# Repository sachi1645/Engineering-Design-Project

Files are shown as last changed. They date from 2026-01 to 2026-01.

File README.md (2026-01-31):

# Wireless Emergency Alert System for Live Performers

> **Group Debuggers** > *Department of Electronic & Telecommunication Engineering, University of Moratuwa*

## 📖 Abstract
Live performance environments demand fast, discreet, and effective communication between performers and the technical crew. Conventional methods such as hand signals or physically reaching out to technicians are inefficient and disruptive. 

This project presents a **Wireless Emergency Alert System** designed specifically for stage performers. Built around a custom PCB featuring the **ESP32-WROOM-32** microcontroller, the wearable device enables one-touch alert transmission over a local Wi-Fi network. Alerts are displayed in real-time on a mobile-responsive web dashboard.

## 🚀 Key Features
* **Real-Time Alerts:** Instantly displays performer name, device ID, and timestamp on the dashboard when the alert button is pressed.
* **Offline Operation:** Runs entirely on a local Wi-Fi network (LAN) with no internet dependency, ensuring reliability in any venue.
* **Audible Notifications:** The dashboard triggers an alert sound to grab the crew's attention during live scenarios.
* **Cross-Platform Dashboard:** A mobile-responsive web app (Flask) that works on laptops, tablets, and phones.
* **Easy Access:** Generates a QR code for the server URL, allowing devices to join the dashboard instantly.
* **Battery Operated:** Powered by a 3.7V 500mAh Li-Po battery with up to 5 hours of active usage.

## 🛠️ Tech Stack
### Hardware
* **Microcontroller:** ESP32-WROOM-32 Chip
* **Power:** 3.7V 500mAh Li-Po Battery with TP4056 Charging Module
* **Connectivity:** 2.4GHz Wi-Fi (Local Network)
* **Interface:** Tactile Push Button, Status LED, Slide Switch

### Software
* **Firmware:** Arduino C++ (HTTP POST, UDP Discovery)
* **Backend:** Python Flask (Web Server, Alert Queue)
* **Frontend:** HTML, CSS, JavaScript (WebSockets for live updates)

## 🏗️ System Architecture
The system consists of two main parts:
1.  **Wearable Transmitter (ESP32):** Reads button inputs and sends alert data via Wi-Fi.
2.  **Central Server (Flask):** Hosted on a PC or Raspberry Pi, it receives alerts and broadcasts them to the dashboard.

**Data Flow:**
`Button Press` -> `ESP32` -> `Wi-Fi Router` -> `Flask Server` -> `Web Dashboard`

## 🔌 Hardware Specifications
| Component | Specification |
|---|---|
| **Current Draw (Idle)** | ~80-100 mA |
| **Current Draw (Peak)** | ~150-160 mA |
| **Battery Life** | ~4-5 Hours (Active) |
| **Charging Time** | ~1.5-2 Hours |

## 🚀 Getting Started

### Prerequisites
* **Hardware:** ESP32 Development Board (or custom PCB), Push Button, LED.
* **Software:** Arduino IDE, Python 3.x.

### 1. Firmware Setup (ESP32)
1.  Open the firmware folder in **Arduino IDE**.
2.  Install the `ESP32` board manager.
3.  Update the `ssid` and `password` variables to match your local router.
4.  Upload the code to the ESP32.

## 👥 Team: Group Debuggers
* **Manitha Ayanaja** - Firmware, Web App, PCB
* **Sachinthaka Dilhara** - PCB Design
* **Kaveesha Divyanga** - Enclosure Design
* **Mishen Janodya** - PCB Design

## 📄 License
This project is submitted for the **EN1190 Engineering Design Project** module at the University of Moratuwa.

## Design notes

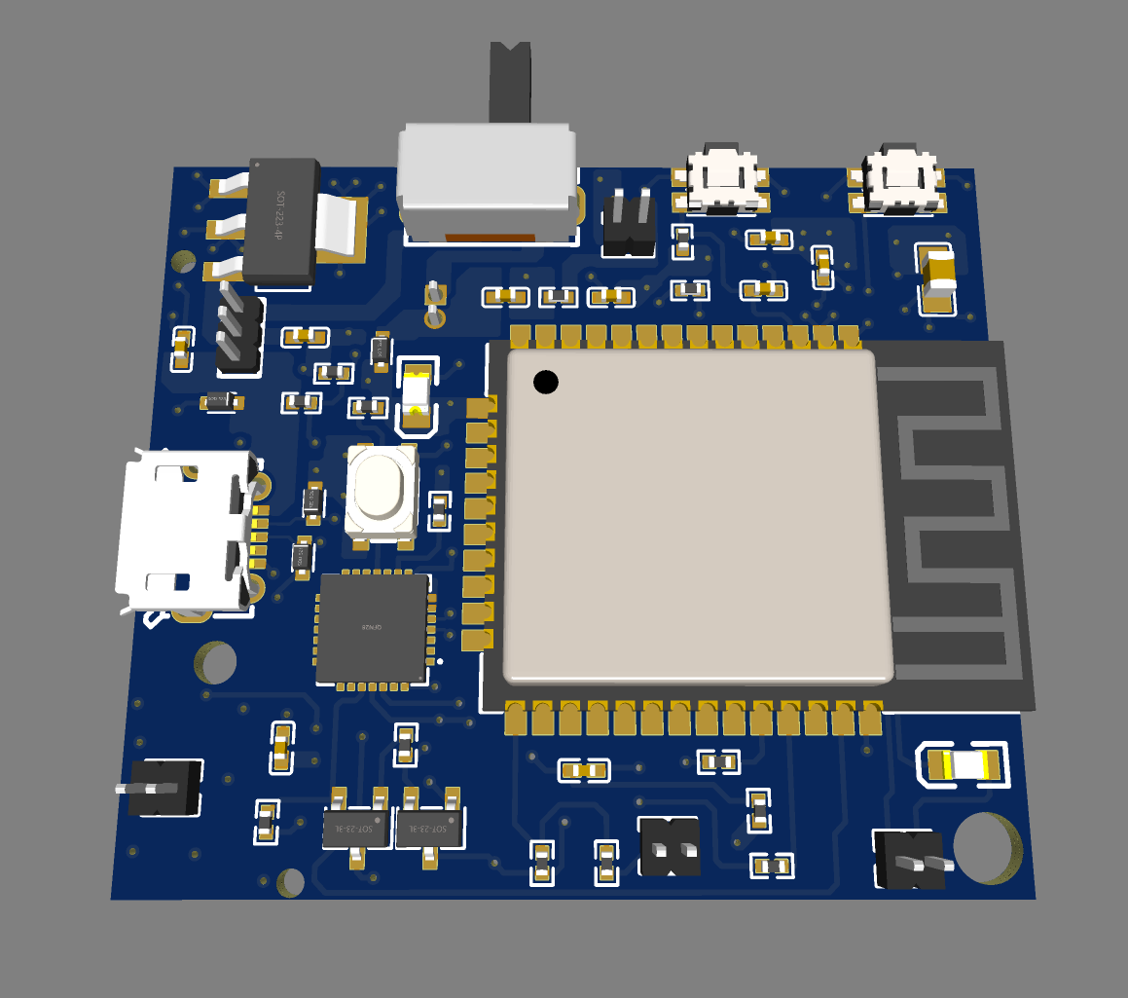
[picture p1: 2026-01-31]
EasyEDA_files/PCB.png

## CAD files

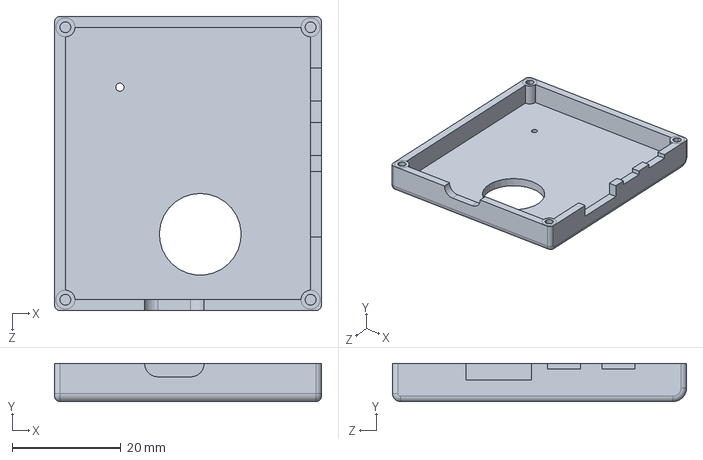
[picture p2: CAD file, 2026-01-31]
Solid_works_design_files/CaseSecond.SLDPRT
49.0 x 7.00 x 54.0 mm

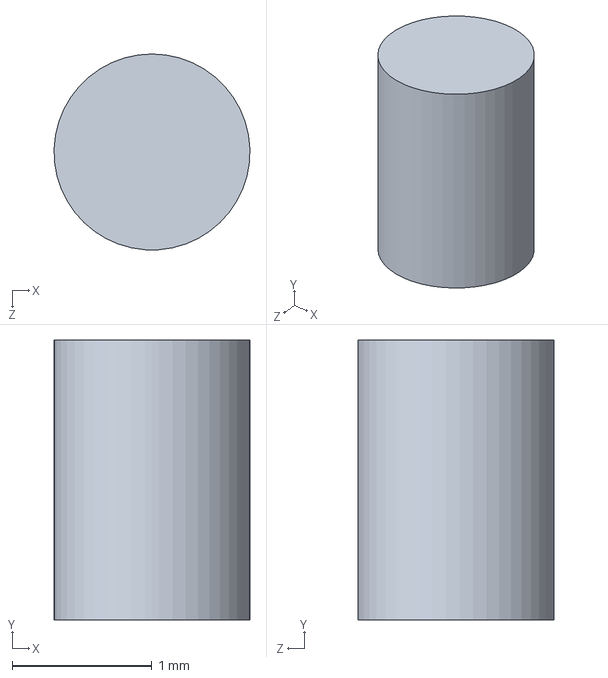
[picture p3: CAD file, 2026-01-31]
Solid_works_design_files/LEDcoverSecond.SLDPRT
1.40 x 2.00 x 1.40 mm

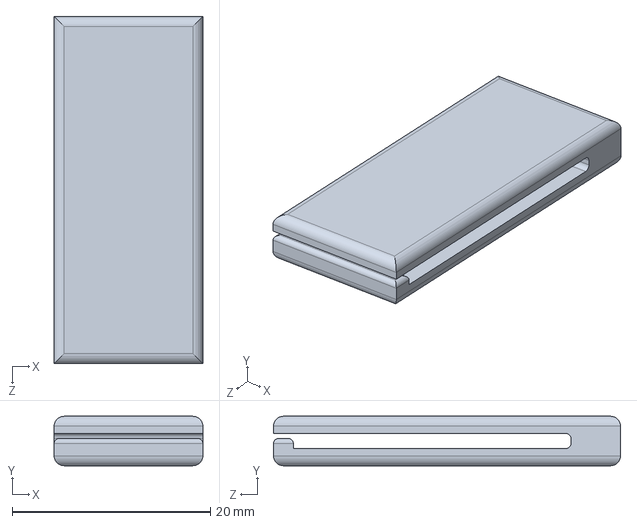
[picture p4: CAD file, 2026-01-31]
Solid_works_design_files/handle.SLDPRT
15.0 x 5.00 x 35.0 mm

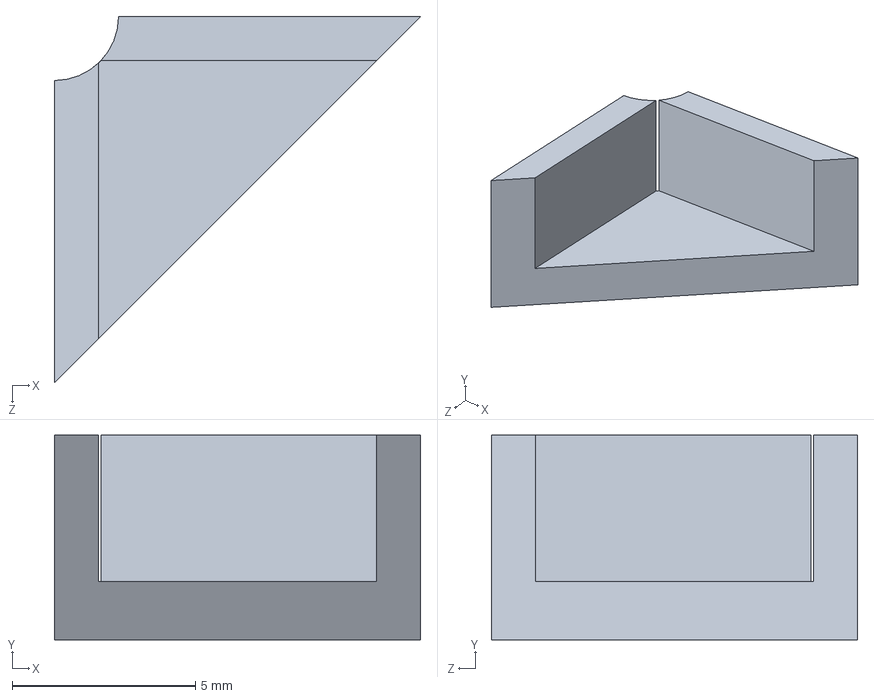
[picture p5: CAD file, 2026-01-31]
Solid_works_design_files/TriangularPieces.SLDPRT
10.0 x 5.60 x 10.0 mm

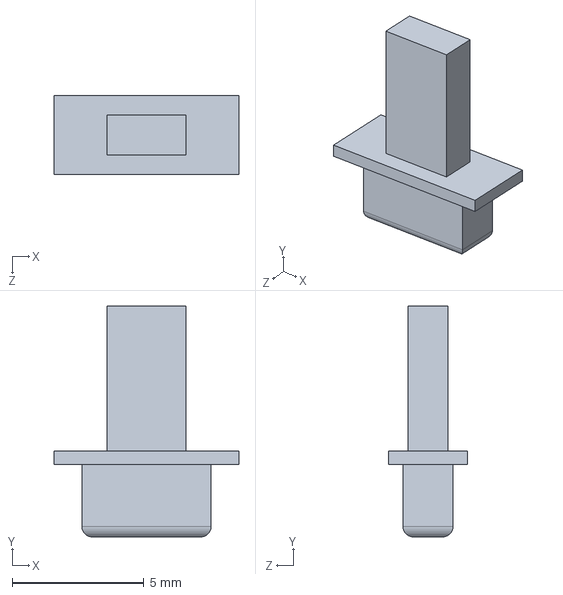
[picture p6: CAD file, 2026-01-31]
Solid_works_design_files/sideButtonsSecond.SLDPRT
7.00 x 8.75 x 3.00 mm

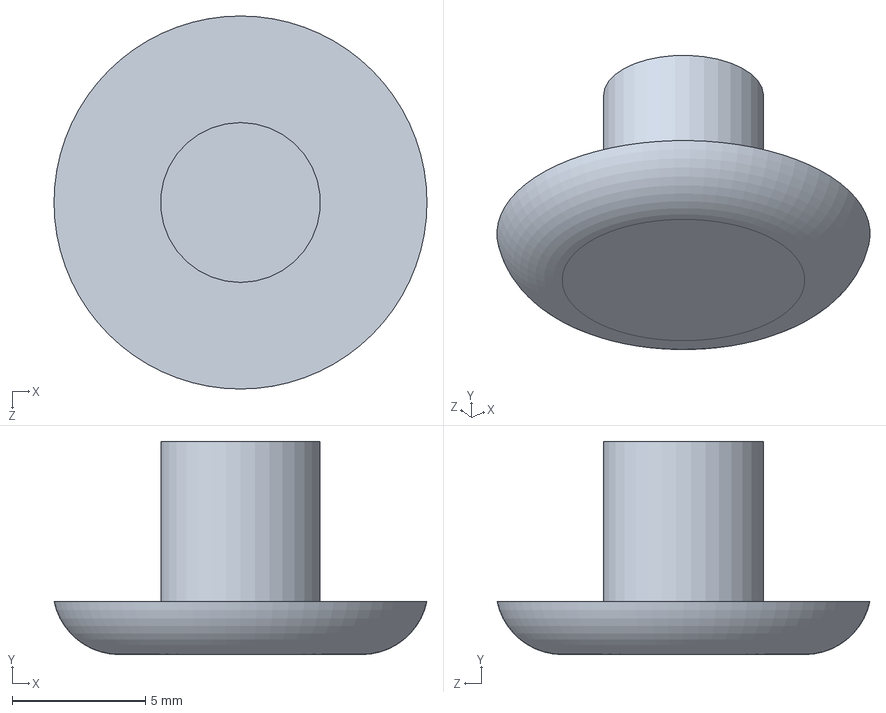
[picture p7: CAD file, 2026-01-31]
Solid_works_design_files/CentreButtonSecond.SLDPRT
14.0 x 8.00 x 14.0 mm

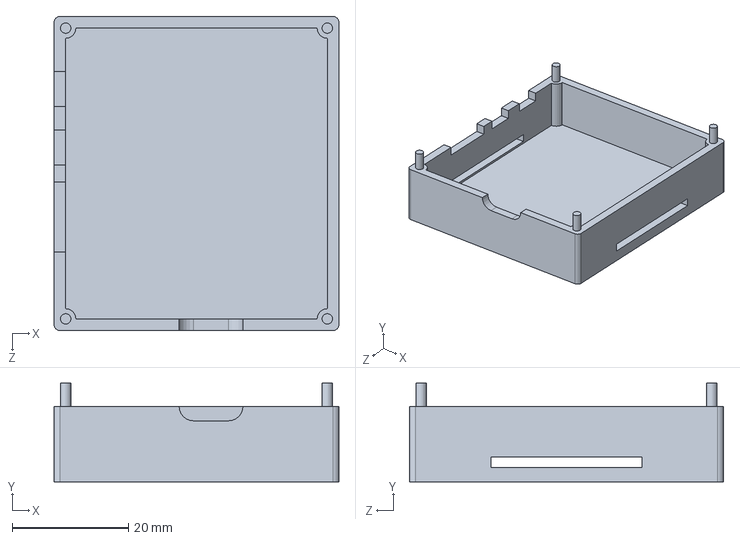
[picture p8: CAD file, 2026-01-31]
Solid_works_design_files/LidSecond.SLDPRT
49.0 x 17.0 x 54.0 mm

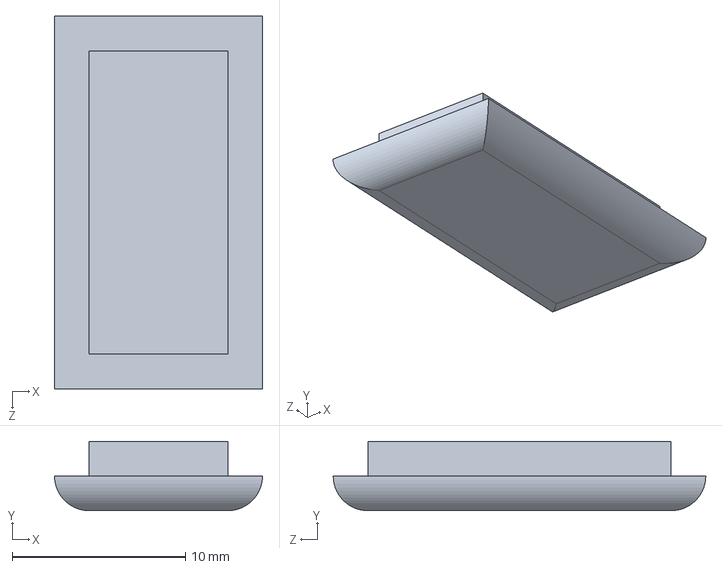
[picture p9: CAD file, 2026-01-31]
Solid_works_design_files/Clip.SLDPRT
12.0 x 4.00 x 21.5 mm

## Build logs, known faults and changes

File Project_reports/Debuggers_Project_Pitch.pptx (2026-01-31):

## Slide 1

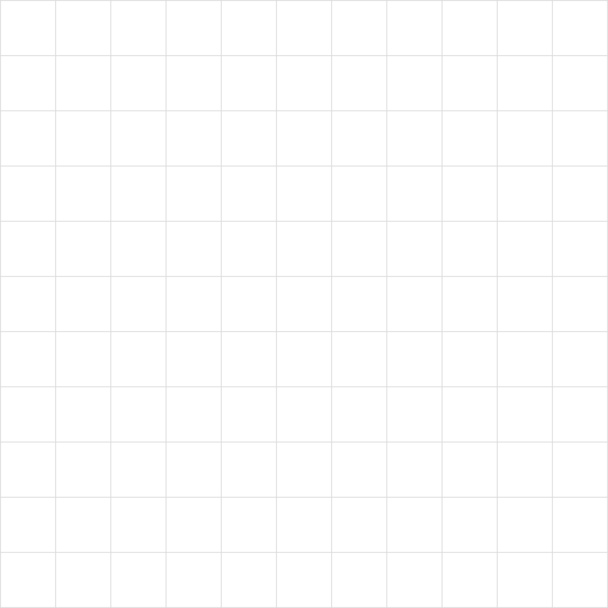
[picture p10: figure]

WIRELESS EMERGENCY ALERT SYSTEM FOR LIVE PERFORMERS

Problem
  - In live shows, artists struggle to silently and quickly notify technical teams of urgent issues.
  - Noise, chaos, and poor visibility make traditional hand signals or shouting ineffective — resulting in delays and disrupted performances

Solution
  - A wearable device with a main centre button
  - Silently notifies the crew in real-time via a web-based dashboard.
  - Ensure zero disruption to the flow of the performance

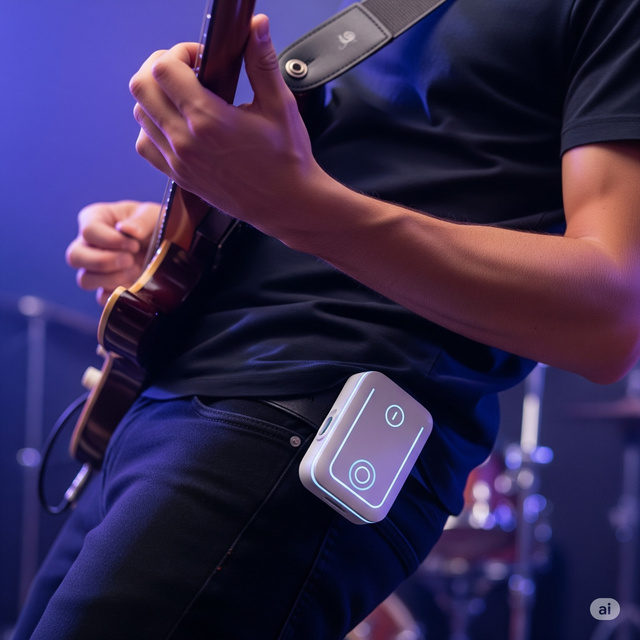
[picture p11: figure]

Key FEATURES

Instant Alerts - Instant alert with performer’s name & timestamp with a single press of a button

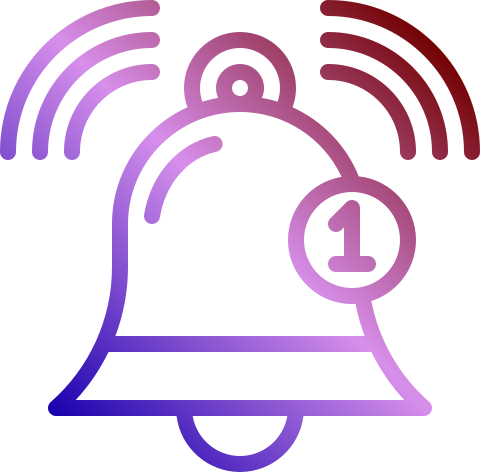
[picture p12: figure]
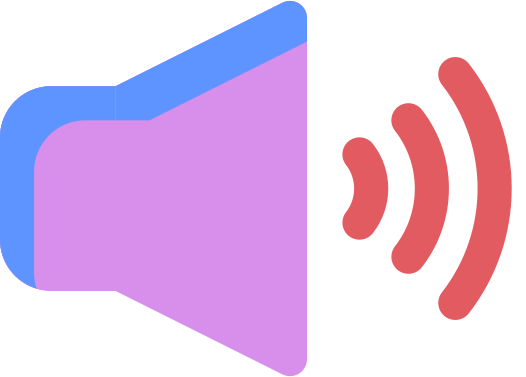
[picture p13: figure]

Audible Notification – Audio buzz to ensure crew attention

Responsive Dashboard – Use on desktop, tablet, or phone — no app required

QR-Based Sharing – Easy dashboard access via dynamic QR code

Auto Network Detection – Smart IP identification for easy setup.

Tab-based UI – Simple controls for sound & sharing

A performer presses a wearable button, triggering a Wi-Fi alert sent to a local Flask server, which instantly updates a real-time crew dashboard accessible via QR code

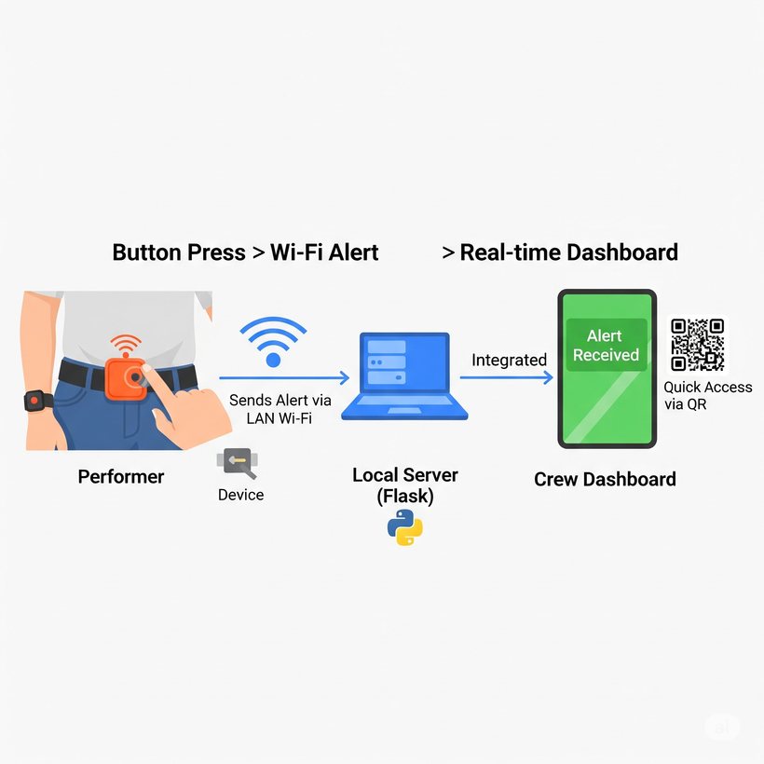
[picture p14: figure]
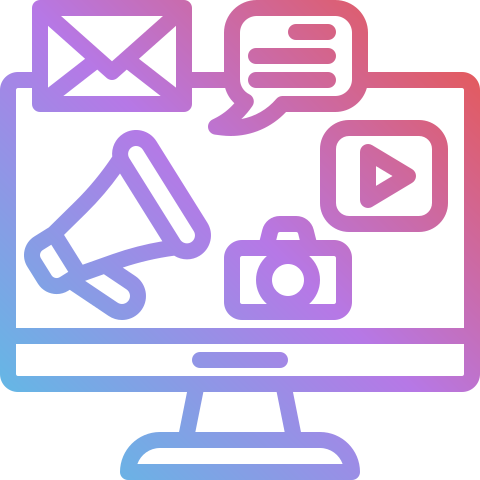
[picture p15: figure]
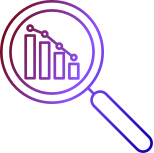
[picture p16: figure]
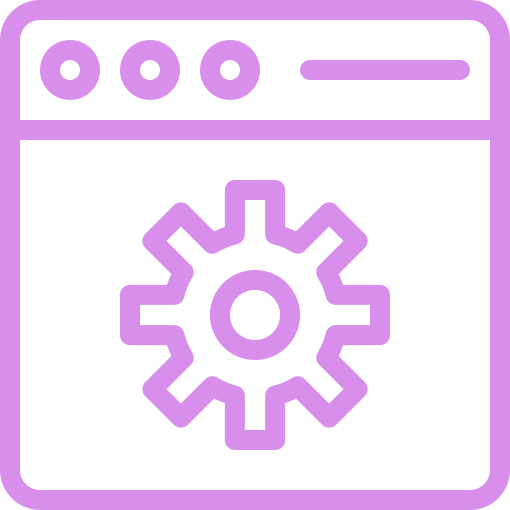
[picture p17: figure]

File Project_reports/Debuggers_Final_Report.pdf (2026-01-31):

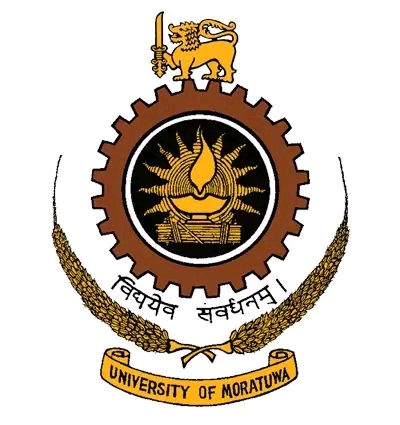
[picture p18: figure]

Department of Electronic & Telecommunication Engineering, University of Moratuwa, Sri Lanka.

# Wireless Emergency Alert System for Live Performers

Group Members:

230065H | Manitha Ayanaja
230147L | Sachinthaka Dilhara
230395T | Kaveesha Divyanga
230248X | Mishen Janodya

Submitted in partial fulfillment of the requirements for the module EN1190 Engineering Design Project Date: July 8, 2025

Wireless Emergency Alert System | Group Debuggers

Abstract Live performance environments demand fast, discreet, and effective communication between performers and technical crew. However, conventional methods such as hand signals or physically reaching out to technicians are inefficient and disruptive. This project presents a wireless emergency alert system designed specifically for stage performers. Built around a custom PCB featuring the ESP32-WROOM-32 microcontroller, the wearable device enables one-touch alert transmission over a local Wi-Fi network. Alerts are displayed in real-time on a mobile-responsive web dashboard, developed using Flask and accessible via QR code. The system operates fully offline, supports multiple users, and is housed in a compact 3D-printed enclosure suitable for live stage use. With positive feedback from local musicians and event organizers, the solution offers a low-cost, scalable alternative to existing bulky or unavailable alert tools in Sri Lanka’s live event industry.

1

## Contents

1 Problem Description | 3
2 Product Feasibility | 3
3 Applications and Extensions | 4
4 Web Application (Dashboard) | 4
5 Product Specifications | 6
6 System Architecture | 6
7 Sketches of Product Design | 8
8 PCB Design | 10
9 Final Product | 11
10 Power Consumption and Battery Performance | 11
11 Market Analysis | 12
12 Marketing, Sales and Beyond | 13
13 Future Improvements | 13
14 Team Task Allocation | 14
15 Final Budget and Pricing | 14

2

## 1 Problem Description

### 1.1 Problem

Live event environments are high-pressure and time-critical. Performers often face technical issues like audio mismatches, faulty monitors, or disconnections, but lack a fast and silent way to inform the crew. A survey conducted among 30+ local musicians and organizers revealed that over 80% experienced such issues and preferred a portable alert system over hand signals. This highlights a strong local demand for a low-cost, silent, real-time communication tool tailored for Sri Lanka’s live music industry.

### 1.2 Expected Goals

| Real-time, silent communication
| LAN-based alert system (no internet dependency)
| Intuitive and non-intrusive device operation

### 1.3 Solution

We designed a compact wearable alert device that sends alerts over a local Wi-Fi network. Each device includes a single button that triggers an alert, displaying the artist’s name and alert icon on a web dashboard for immediate crew response.

### 1.4 Justification of Selection

Selected for its simplicity, low component cost, fast deployment, and relevance to the live performance environment. It directly addresses a critical problem in a novel and efficient way.

## 2 Product Feasibility

### 2.1 Technical Feasibility

The system architecture includes two parts: a wearable transmitter and a Flask-based web server running on a laptop or Raspberry Pi. The ESP32 communicates over Wi-Fi with the server. The server includes UDP discovery, real-time alert queueing, and a local dashboard. WebSockets enable real-time updates.
All components used in this project—ESP32-WROOM-32 chip, TP4056, Li-Po batteries, and SMD parts—are readily available from local suppliers. The software is based on the lightweight Flask framework and has been tested in offline conditions. The alert mechanism has been tested using a simulated concert setup and performs reliably over a typical 3–4 hour show. LED indicators provide live status feedback, and the battery supports up to upto 5 hours of standby time on a full charge.

### 2.2 Hardware Feasibility

| ESP32-WROOM-32 chip
| TP4056 Charging Module for Li-Po battery
| Slide switch for power control
| Compact 3D-printed enclosure with button access
| Status LED for feedback

3

### 2.3 Software Feasibility

| ESP32 Firmware (Arduino C++): Wi-Fi config, alert button logic, server discovery via UDP
| Web Server (Python Flask): Web app, alert queue, dashboard
| HTML/CSS/JavaScript: Frontend for display

## 3 Applications and Extensions

Applications:

| Live concerts and music festivals
| School or university performances
| Theater productions
| Emergency signaling for disabled performers

Future Extensions:

| Multi-role access (organizer/crew dashboard view)
| Alert classification (instrument, monitor, lighting)
| Mobile dashboard app

## 4 Web Application (Dashboard)

The web application is a key component of the Wireless Emergency Alert System, acting as the central interface for the technical crew to monitor live alerts from performers. Designed using Flask (Python) for the backend and HTML/CSS/JavaScript for the frontend, it runs locally on a PC.

### 4.1 Key Features:

| Real-Time Alert Display: When a performer presses the button on their wearable device, the alert is instantly displayed on the dashboard with the device name and timestamp.
| Audio Notification: A built-in alert sound helps grab attention during live scenarios, ensur- ing no alert goes unnoticed.
| Responsive Design: The dashboard is optimized for both desktops and mobile devices, enabling use on tablets or phones without requiring any additional apps.
| QR Code Sharing: The app generates a QR code containing the server URL, allowing other users on the same network to join the dashboard instantly.
| Network Device Discovery: The system supports detection of server IP addresses dynam- ically, making the setup process easier in multi-device networks.
| Tab-based Sidebar: The user interface includes tabs for “Sound Settings” and “Dashboard Sharing,” improving user control and configuration.

### 4.2 Technical Highlights:

| Built using Flask’s Jinja2 templating to dynamically render alerts.
| WebSockets and JavaScript ensure live updates without page refresh.
| Compatible with all modern browsers with zero installation required.
| 4

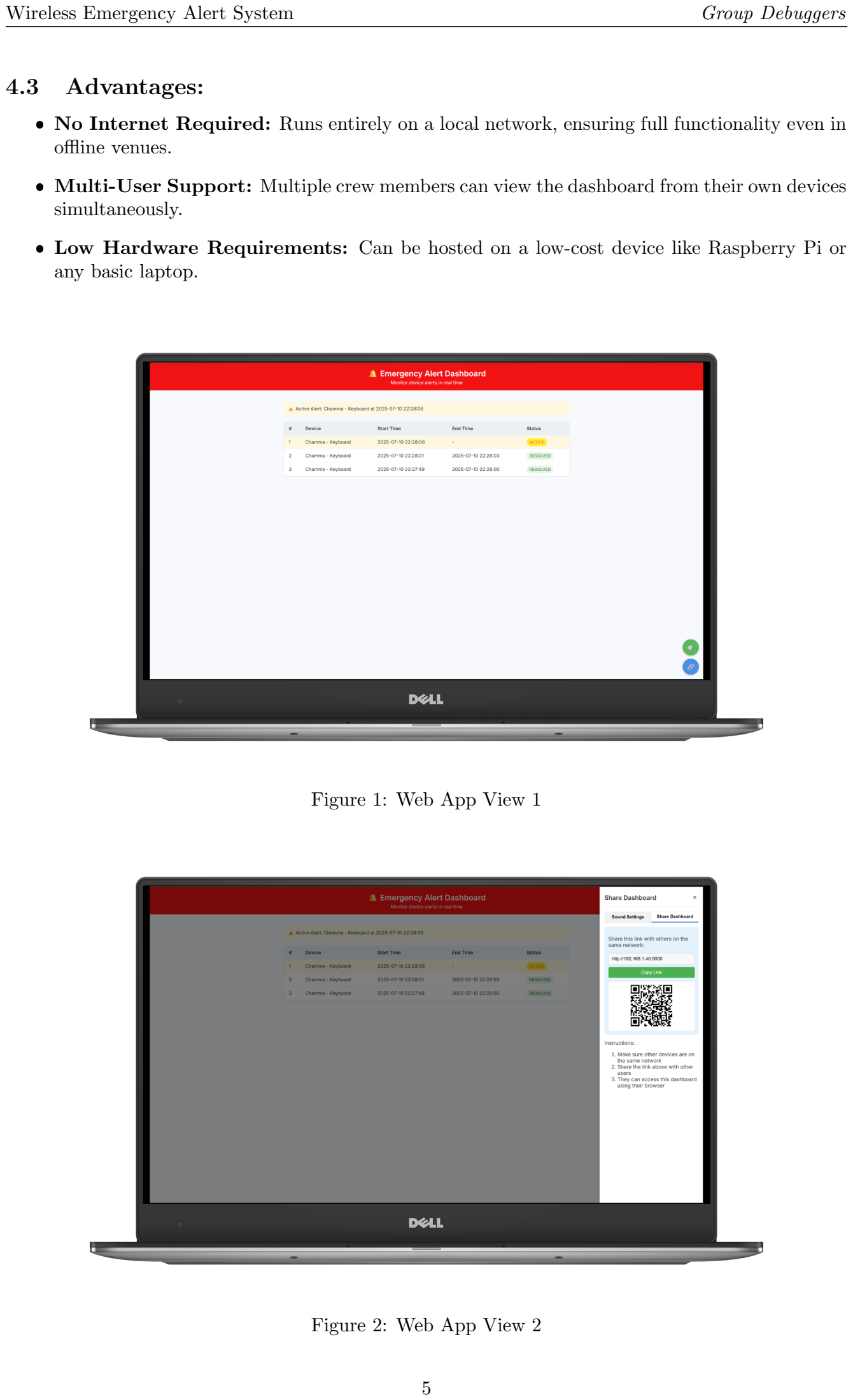
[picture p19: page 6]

### 4.3 Advantages:

| No Internet Required: Runs entirely on a local network, ensuring full functionality even in offline venues.
| Multi-User Support: Multiple crew members can view the dashboard from their own devices simultaneously.
| Low Hardware Requirements: Can be hosted on a low-cost device like Raspberry Pi or any basic laptop.

Figure 1: Web App View 1

Figure 2: Web App View 2

5

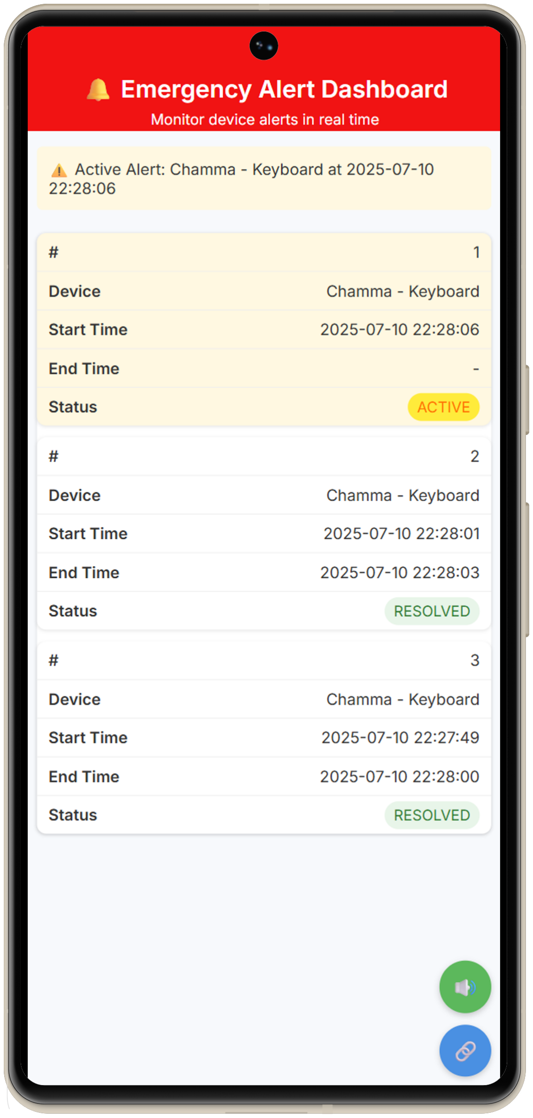
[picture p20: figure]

Figure 3: Mobile View

## 5 Product Specifications

| Microcontroller: ESP32-WROOM-32 Chip
| Connectivity: 2.4GHz Wi-Fi, local-only
| Power: 3.7V 500mAh Li-Po rechargeable
| Charging: Micro-USB via TP4056
| Alert Interface: Tactile push button, LED feedback
| Enclosure: Custom 3D print, clip-on or belt-mount

## 6 System Architecture

The product is designed as a modular system consisting of hardware and software components that together facilitate seamless emergency communication during live performances. The architecture is divided into the following key blocks:

| ESP32 Control Unit: Acts as the brain of the system. It reads input from the alert button, handles Wi-Fi connectivity, and sends alert data to the server.
| 6

| User Interface: Includes a tactile alert push button, two side buttons (for Wi-Fi reconnect and artist info reset), and a status LED that blinks upon alert transmission.
| Power Supply: A rechargeable 3.7V 500mAh Li-Po battery powers the device. It is managed via a TP4056 charging module with a slide switch for manual ON/OFF control.
| Web Server (Flask): Hosted on a local PC or Raspberry Pi. It receives alerts from ESP32 and updates the dashboard in real-time using WebSockets.
| Web Dashboard: A browser-accessible UI that displays live alerts with timestamps. It also provides QR sharing, sound settings, and is mobile-optimized.

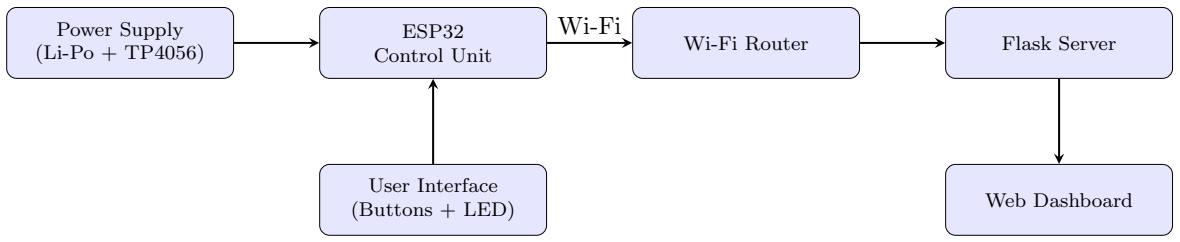
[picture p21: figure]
Power Supply (Li-Po + TP4056); ESP32 Control Unit; User Interface (Buttons + LED); Wi-Fi Router; Flask Server; Web Dashboard

Figure 4: Compact Block Diagram

Design Notes

| The ESP32 firmware is written in Arduino C++, using HTTP POST and UDP for server discovery.
| The web server uses Flask with WebSocket integration for real-time updates.
| All components are placed on a compact custom PCB with SMD components.
| The enclosure design ensures quick access to buttons while protecting internal components during live events.
| Two auxiliary buttons on the side allow easy Wi-Fi reconnection and artist ID reset without external tools.

Note on Deviations: The design followed the original plan with no major deviations. However, two extra buttons were added as enhancements to provide on-device resetting and Wi-Fi reconnect features.

7

## 7 Sketches of Product Design

### 7.1 Initial Sketch

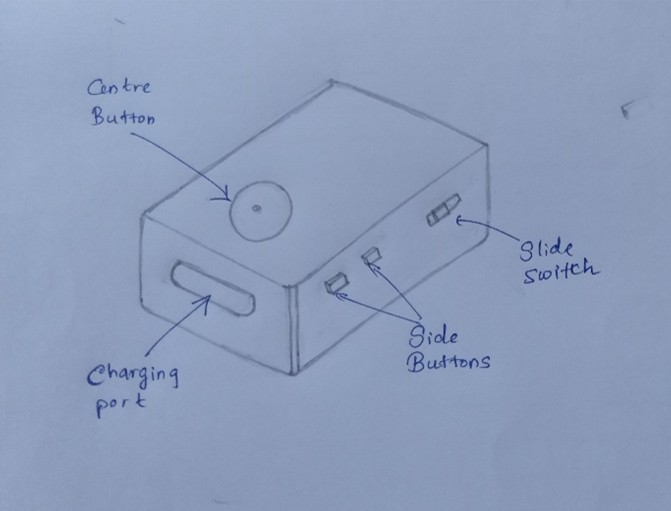
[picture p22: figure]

Figure 5: Initial Sketch

8

### 7.2 Final Design

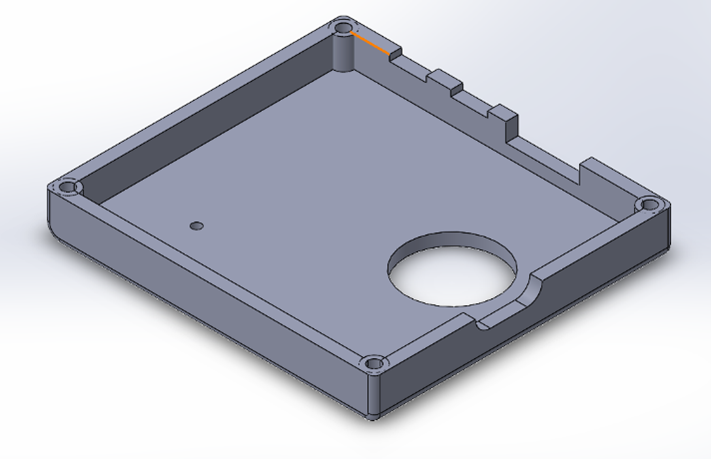
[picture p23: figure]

Figure 6: Upper Lid

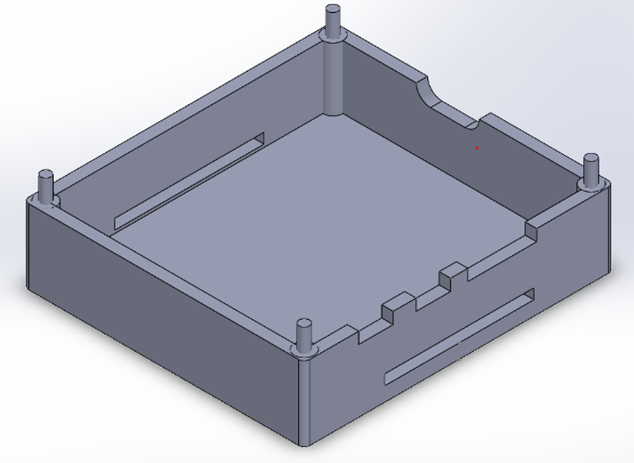
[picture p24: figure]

Figure 7: Lower Lid

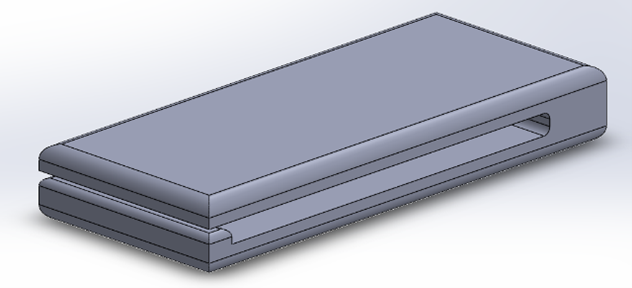
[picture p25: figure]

Figure 8: Handle

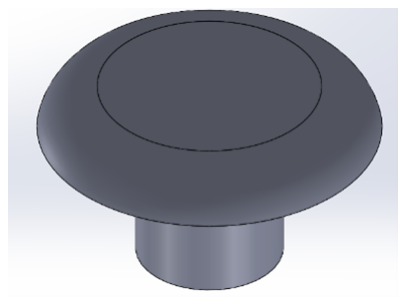
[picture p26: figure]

Figure 9: Center Button

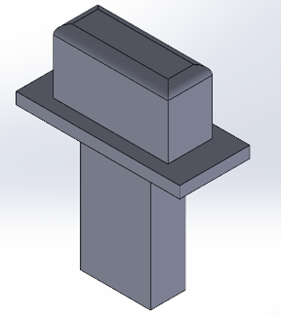
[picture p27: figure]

Figure 10: Side Button
9

## 8 PCB Design

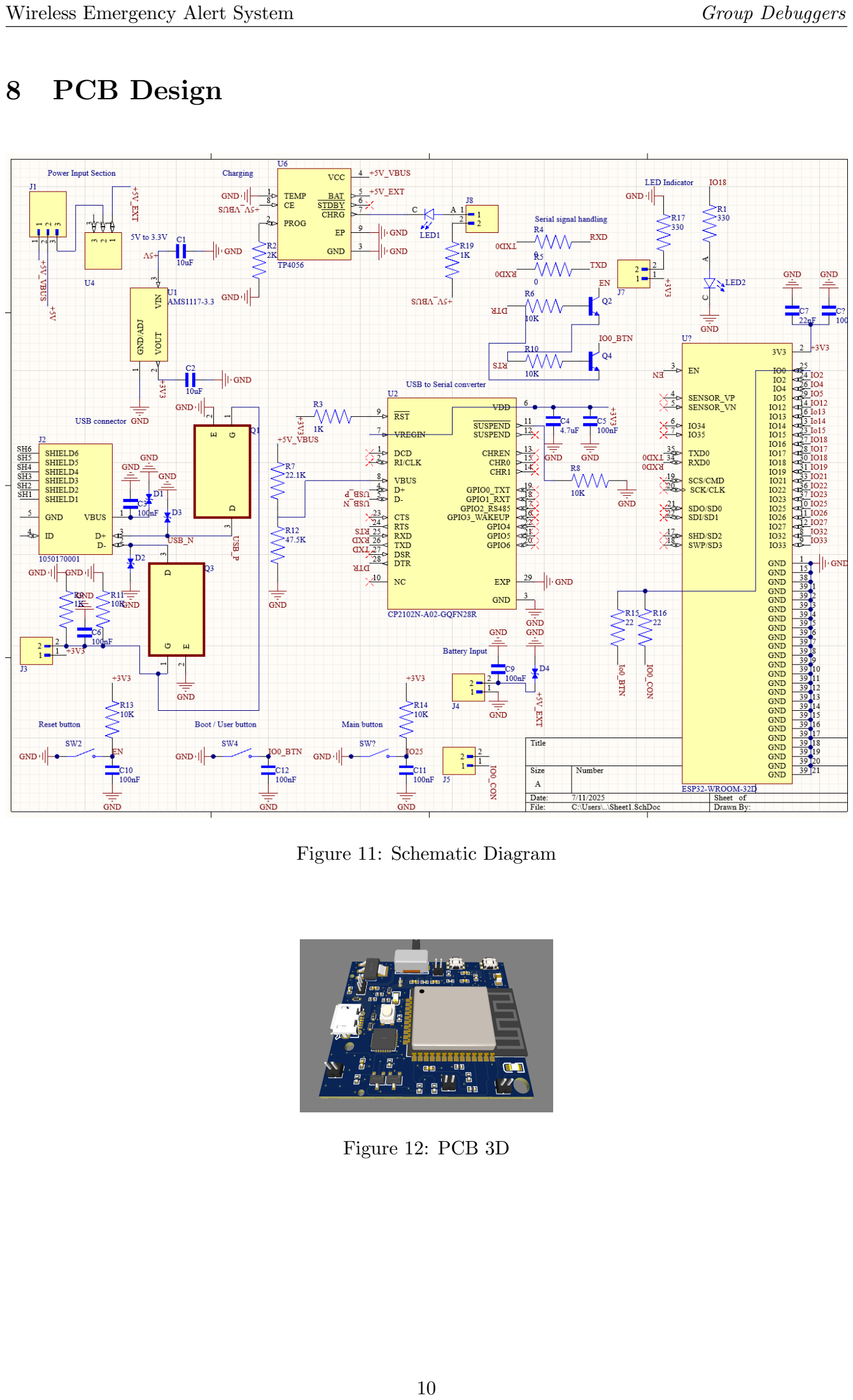
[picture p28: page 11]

Figure 11: Schematic Diagram

Figure 12: PCB 3D

10

## 9 Final Product

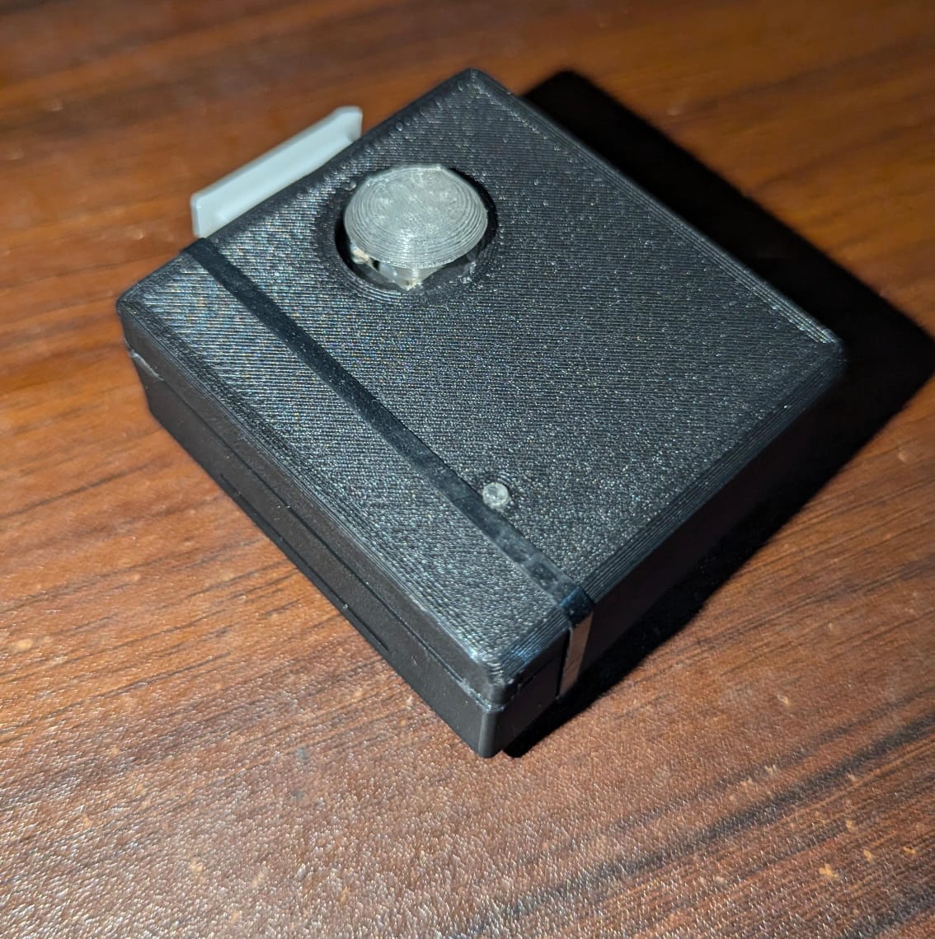
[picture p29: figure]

Figure 13: Front View

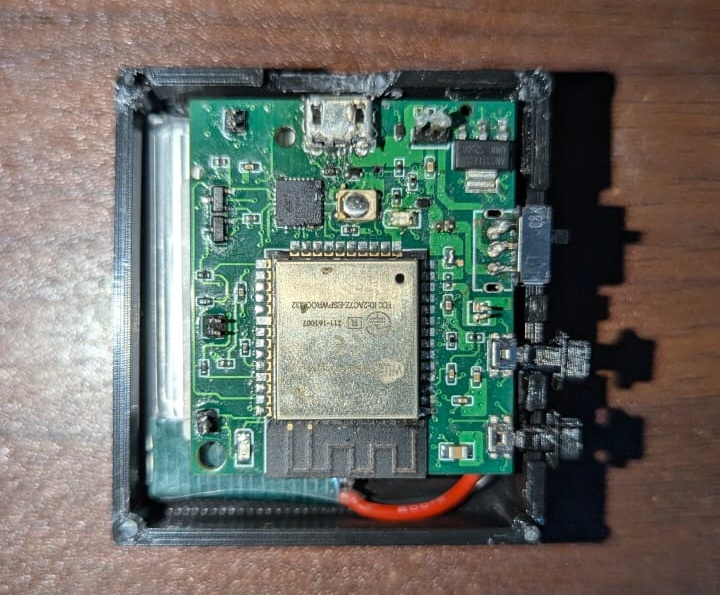
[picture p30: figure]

Figure 14: Internal View

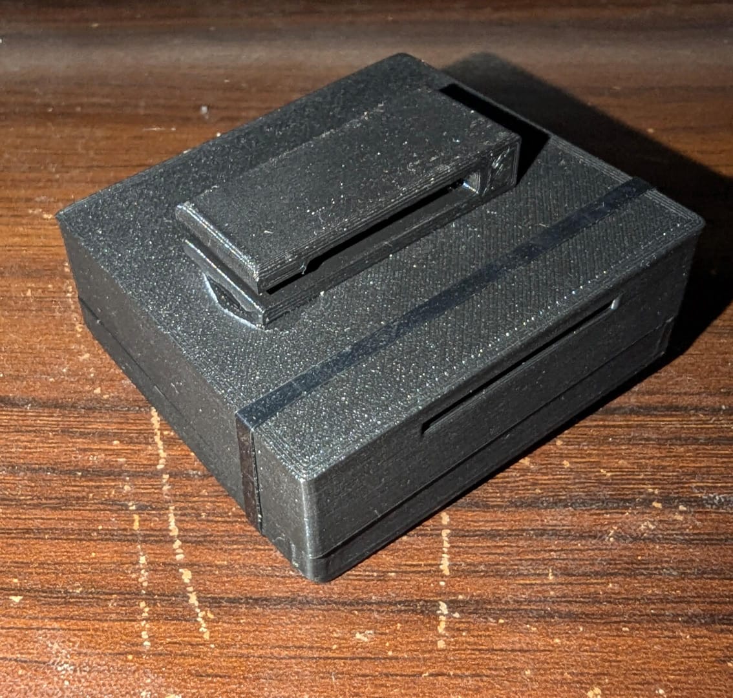
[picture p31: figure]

Figure 15: Rear View

## 10 Power Consumption and Battery Performance

The device is designed to operate efficiently during typical concert durations, while ensuring reliable wireless connectivity and alert functionality.

Power Source

| Battery Type: 3.7V 500mAh Li-Po rechargeable battery
| Charging Module: TP4056 with micro-USB (5V input)

Measured Current Draw

| Idle Mode (Wi-Fi connected): ∼80–100 mA
| During Alert Transmission: Peaks at ∼150–160 mA (for a few seconds)

11

Battery Life Estimate

The estimated battery life is calculated using average consumption:

Average consumption ≈ 90 mA ⇒

500 mAh
90 mA ≈ 5.5 hours

Expected Usage Time per Charge: 4–5 hours of continuous Wi-Fi connection (realistic usage in live events)

Charging Time: ∼1.5–2 hours (via standard 5V USB power supply)

Conclusion

The battery is sufficient for most concerts and rehearsals, which typically last 2–4 hours. The device is designed for daily charging, similar to other stage equipment.

## 11 Market Analysis

The Wireless Emergency Alert System is specifically designed for musicians, stage performers, and technical crew members in live entertainment settings. Its primary target audience includes music bands, audio technicians, university concerts, school events, theater productions, and other stage-based performances where quick, non-verbal communication is critical. Based on a detailed survey conducted among over 30 individuals in the industry — including guitarists, drummers, singers, and event organizers — a clear need for such a system was identified. Commonly reported issues include:

| In-ear monitor failures
| Audio level mismatches
| Instrument disconnections
| Delay in reaching technicians during live performances

Traditional communication methods such as hand signals or physically approaching technicians were found to be disruptive and inefficient. Respondents expressed a preference for portable alert systems that are silent, reliable, and easy to use during performances.

### 11.1 Key Advantages

Our system offers several competitive benefits:

Affordable: Estimated cost of LKR 7,500 per device falls well within the expected user budget (LKR 2,000–15,000).

| Offline Operation: No internet required. Operates entirely on a local Wi-Fi network.
| Custom PCB Design: Built using a custom PCB with SMD components and the ESP32-
WROOM-32 chip, ensuring compact size and reliability.

Scalable: Supports multiple performers simultaneously. A typical band setup can have each member using their own device.

Customizable: Software and dashboard can be adapted for different stage roles or alert categories upon request.

Dashboard Access: Alerts are displayed in real-time on a mobile-friendly web dashboard, accessible via QR code or local IP.

12

### 11.2 User Feedback

Although the system has not yet been tested in a live concert, direct feedback from musicians and event organizers has been highly positive. Many expressed interest in:

| Vibration and LED feedback (for quiet environments)
| Visual dashboards for audio engineers
| Multi-device accessibility

These responses validate both the demand and practicality of the product, especially in the Sri Lankan performance sector where such tools are largely unavailable or cost-prohibitive. Our system fills this gap with a market-ready, locally-built, and cost-effective solution.

## 12 Marketing, Sales and Beyond

Marketing Strategy:

| Direct outreach to pofessional bands, gig players, technicians, and live event organizers.
| Leverage demo sessions and word-of-mouth from music professionals.
| Use social media to showcase the device and market.

Sales Model:

| Sell units in packs (e.g., 5-unit starter packs) for typical band setups.
| Provide QR-code based dashboard access, plug-and-play experience.
| Offer software customization for specific stage roles or device naming.

Scalability:

| The system supports multiple wearable devices connected to a single server.
| Server software allows dynamic addition/removal of users.

Support Plans:

| Include user manual with each pack.
| Provide optional updates, remote setup help, and warranty for up to 6 months.

## 13 Future Improvements

The system currently fulfills its intended use; however, we plan the following enhancements:

| Vibration Alert Module: For silent environments like acoustic concerts or theaters.
| OLED Display Integration: To show alert confirmation, battery status, or role name.
| Mobile App Companion: To enable organizers to send alerts back to performers.
| Battery Indicator LEDs: To show real-time battery level and charging status.
| Wi-Fi Mesh Support: To improve coverage in larger venues or outdoor stages.

13

## 14 Team Task Allocation

Name | Task Description
Manitha Ayanaja (230065H) | Firmware programming, web application development, dashboard UI, soldering, PCB designing
Sachinthaka Dilhara (230147L) | PCB designing, soldering
Kaveesha Divyanga (230395T) | Enclosure designing, soldering
Mishen Janodya (230248X) | PCB designing, soldering

Table 1: Task Allocation

## 15 Final Budget and Pricing

Component | Price (Rs.)
ESP32-WROOM-32 Chip Custom PCB PCB Components Li-Po Battery 3D Printed Enclosure Miscellaneous Expenses | 800 540 3500 730 1200 1000
Total Cost Per Device | Rs. 7,770

Table 2: Final Prototype Bill of Quantities

Selling Price Justification

To ensure long-term sustainability and profitability, we propose a selling model based on batch sales:

| Target Market: Music bands with 5–7 performers typically order in sets.
| Profit Margin: A margin of 20% is added to the production cost.
| Final Price: Rs. 7,770 × 1.2 = Rs. 9,324 (rounded to Rs. 9,350)

Thus, a 5-unit band pack would be offered at Rs. 46,750, competitive and practical for the local market.

14

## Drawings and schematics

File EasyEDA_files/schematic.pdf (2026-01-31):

# EDP Project

# POWER INPUT SELECTION

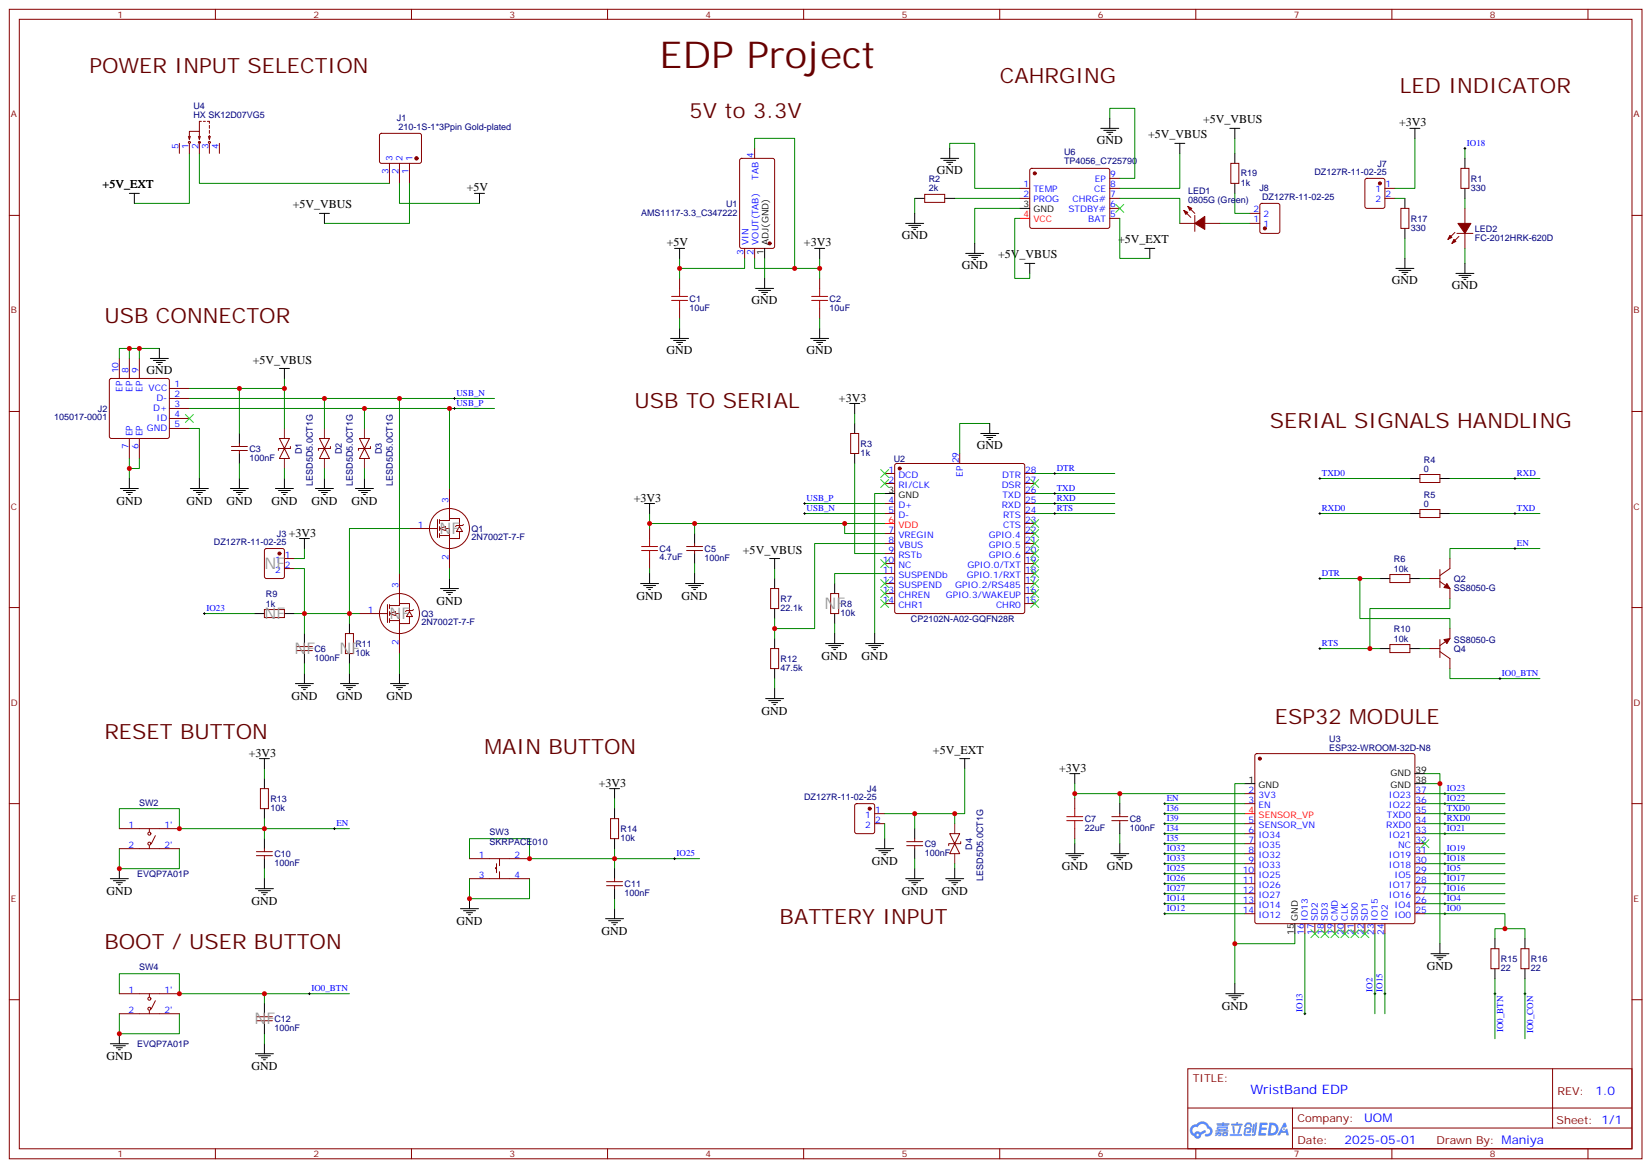
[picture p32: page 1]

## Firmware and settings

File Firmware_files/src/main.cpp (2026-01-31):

#include <WiFi.h>
#include <WebServer.h>
#include <HTTPClient.h>
#include <EEPROM.h>
#include <DNSServer.h>
#include <WiFiUdp.h>

void handleRoot();
void handleSave();
void startCaptivePortal();
void connectToWiFi();
void sendAlert(bool state);
void toggleAlertState();
void checkForResetCondition();
void triggerReset();
bool reconnectWiFi();
String discoverServer();
void blinkLED(bool stop = false, unsigned long interval = 0);
void printNetworkInfo();
String improvedDiscoverServer();
void improvedCaptivePortal();
bool enhancedWiFiConnect();
void networkDiagnostics();

// Pins
const int buttonPin = 25;
const int ledPin = 18;
const int bootButtonPin = 0;

// Network
const int UDP_PORT = 12345;
const char* UDP_REQUEST = "WHERE_IS_SERVER";
WiFiUDP udp;

// Configuration
struct Config {
  char ssid[32];
  char password[32];
  char deviceName[32];
  bool configured;
};

// State
Config config;
WebServer server(80);
DNSServer dnsServer;
bool alertState = false;
unsigned long lastDebounceTime = 0;
const unsigned long debounceDelay = 500;
unsigned long buttonPressStartTime = 0;
bool resetTriggered = false;
bool serverConnected = false;

// LED blinking variables
bool isBlinking = false;
unsigned long lastBlinkTime = 0;
const unsigned long blinkInterval = 300; // Fast blink interval in ms
const unsigned long serverBlinkInterval = 1000; // Slow blink interval for server disconnect
bool ledState = false;
unsigned long lastServerCheckTime = 0;
const unsigned long serverCheckInterval = 10000; // Check server every 10 seconds

void setup() {
  Serial.begin(115200);
  Serial.println("\n\n=== ESP32 Emergency Alert System Starting ===");
  
  pinMode(buttonPin, INPUT_PULLUP);
  pinMode(ledPin, OUTPUT);
  pinMode(bootButtonPin, INPUT);

  // Initialize LED state
  digitalWrite(ledPin, LOW);
  ledState = false;
  alertState = false;
  serverConnected = false;

  EEPROM.begin(sizeof(Config));
  EEPROM.get(0, config);

  Serial.println("Checking for reset condition...");
  checkForResetCondition();

  if (!config.configured) {
    Serial.println("Device not configured, starting setup mode...");
    // Start blinking LED to indicate setup mode
    isBlinking = true;
    startCaptivePortal();
  } else {
    Serial.println("Device configured, connecting to WiFi...");
    // Start blinking LED while connecting to WiFi
    isBlinking = true;
    connectToWiFi();
  }
  
  networkDiagnostics();
}

void loop() {
  // Handle LED blinking if necessary
  if (isBlinking) {
    unsigned long currentInterval = !config.configured ? blinkInterval : 
                                   (WiFi.status() == WL_CONNECTED && !serverConnected) ? serverBlinkInterval : 
                                   blinkInterval;
    blinkLED(false, currentInterval);
  }
  
  // Reset button check
  if (digitalRead(bootButtonPin) == LOW && !resetTriggered) {
    if (buttonPressStartTime == 0) {
      buttonPressStartTime = millis();
      Serial.println("Boot button pressed, hold for factory reset...");
    } else if (millis() - buttonPressStartTime > 3000) {
      triggerReset();
    }
  } else {
    buttonPressStartTime = 0;
  }

  // If configured, check connection status periodically
  if (config.configured && WiFi.status() == WL_CONNECTED) {
    // Periodically check if server is available
    if (millis() - lastServerCheckTime > serverCheckInterval) {
      lastServerCheckTime = millis();
      
      Serial.println("Performing periodic server check...");
      String serverIP = discoverServer();
      
      if (serverIP.isEmpty()) {
        Serial.println("Server not found on this check");
        if (serverConnected || !isBlinking) {
          // Server disconnected, start slow blinking
          serverConnected = false;
          isBlinking = true;
          Serial.println("Server disconnected/unavailable - starting indicator blinking");
        }
      } else {
        Serial.print("Server found at: "); Serial.println(serverIP);
        if (!serverConnected) {
          // Server connected, stop blinking
          serverConnected = true;
          
          if (isBlinking) {
            // Stop blinking and set LED to reflect alert state
            blinkLED(true);
            Serial.println("Server connected - stopping indicator blinking");
          }
        }
      }
    }
    
    // Alert button check with debounce (only if server is connected)
    if (serverConnected && digitalRead(buttonPin) == LOW && millis() - lastDebounceTime > debounceDelay) {
      lastDebounceTime = millis();
      Serial.println("Alert button pressed");
      toggleAlertState();
    }
  } else if (config.configured && WiFi.status() != WL_CONNECTED) {
    // If WiFi disconnected, attempt to reconnect periodically
    if (millis() - lastServerCheckTime > serverCheckInterval) {
      lastServerCheckTime = millis();
      Serial.println("WiFi disconnected, attempting to reconnect...");
      reconnectWiFi();
    }
  }
  
  // Handle captive portal if not configured
  if (!config.configured) {
    dnsServer.processNextRequest();
    server.handleClient();
  }
}

void blinkLED(bool stop, unsigned long interval) {
  if (stop) {
    isBlinking = false;
    // Ensure LED properly reflects current alert state when blinking stops
    ledState = alertState;
    digitalWrite(ledPin, alertState ? HIGH : LOW);
    Serial.print("Blinking stopped. LED set to: "); Serial.println(alertState ? "ON" : "OFF");
    return;
  }
  
  unsigned long actualInterval = interval > 0 ? interval : blinkInterval;
  
  if (isBlinking && millis() - lastBlinkTime > actualInterval) {
    lastBlinkTime = millis();
    ledState = !ledState;
    digitalWrite(ledPin, ledState ? HIGH : LOW);
  }
}

void toggleAlertState() {
  alertState = !alertState;
  ledState = alertState; // Keep ledState in sync with alertState
  digitalWrite(ledPin, alertState ? HIGH : LOW);
  Serial.print("Alert state toggled to: "); Serial.println(alertState ? "ON" : "OFF");
  sendAlert(alertState);
}

void sendAlert(bool state) {
  if (WiFi.status() != WL_CONNECTED) {
    Serial.println("WiFi not connected, cannot send alert");
    if (!reconnectWiFi()) {
      // Could not reconnect, revert alert state
      alertState = !alertState;
      ledState = alertState;
      digitalWrite(ledPin, alertState ? HIGH : LOW);
      Serial.println("Could not reconnect to WiFi, alert state reverted");
      return;
    }
  }

  String serverIP = discoverServer();
  if (serverIP.isEmpty()) {
    Serial.println("Server discovery failed, cannot send alert");
    // Server not available, set status
    serverConnected = false;
    isBlinking = true;
    // Revert alert state
    alertState = !alertState;
    Serial.println("Server not available, alert state reverted");
    return;
  }

  // Server is available
  serverConnected = true;
  
  HTTPClient http;
  String url = "http://" + serverIP + ":5000/alert";
  Serial.print("Sending alert to: "); Serial.println(url);
  
  http.begin(url);
  http.addHeader("Content-Type", "application/x-www-form-urlencoded");
  
  String postData = "name=" + String(config.deviceName);
  Serial.print("POST data: "); Serial.println(postData);
  
  int httpCode = http.POST(postData);
  
  if (httpCode > 0) {
    String response = http.getString();
    Serial.print("Alert "); 
    Serial.print(state ? "activated" : "deactivated");
    Serial.print(" with HTTP code: ");
    Serial.print(httpCode);
    Serial.print(" - Response: ");
    Serial.println(response);
  } else {
    Serial.print("HTTP error: ");
    Serial.println(http.errorToString(httpCode).c_str());
    // Revert state if failed
    alertState = !alertState;
    ledState = alertState; // Keep ledState in sync with alertState
    digitalWrite(ledPin, alertState ? HIGH : LOW);
    Serial.println("HTTP request failed, alert state reverted");
  }
  http.end();
}

bool reconnectWiFi() {
  // Start blinking while reconnecting
  isBlinking = true;
  Serial.print("Reconnecting to WiFi: "); Serial.println(config.ssid);
  
  WiFi.reconnect();
  int attempts = 0;
  while (WiFi.status() != WL_CONNECTED && attempts < 5) {
    delay(500);
    Serial.print(".");
    attempts++;
  }
  
  if (WiFi.status() == WL_CONNECTED) {
    Serial.println("\nReconnected to WiFi!");
    printNetworkInfo();
    
    // Check server connection
    String serverIP = discoverServer();
    if (serverIP.isEmpty()) {
      Serial.println("Server unavailable after WiFi reconnect.");
      serverConnected = false;
      // Continue blinking but at slower rate
      isBlinking = true;
      return true; // WiFi connected but server not available
    } else {
      Serial.println("Server found at: " + serverIP);
      serverConnected = true;
      // Stop blinking, everything is connected
      blinkLED(true);
      return true;
    }
  } else {
    Serial.println("\nWiFi reconnection failed!");
    serverConnected = false;
    // Continue fast blinking to indicate WiFi connection issue
    return false;
  }
}

String discoverServer() {
  return improvedDiscoverServer();
}

String improvedDiscoverServer() {
  Serial.println("Attempting server discovery...");
  
  // Try 3 times
  for (int attempt = 0; attempt < 3; attempt++) {
    Serial.print("Discovery attempt "); Serial.println(attempt + 1);
    
    udp.beginPacket("255.255.255.255", UDP_PORT);
    udp.write((const uint8_t*)UDP_REQUEST, strlen(UDP_REQUEST));
    udp.endPacket();
    
    unsigned long start = millis();
    while (millis() - start < 1000) { // 1 second per attempt
      int packetSize = udp.parsePacket();
      if (packetSize) {
        char buffer[16];
        int len = udp.read(buffer, 15);
        buffer[len] = '\0';
        Serial.print("Server found at: "); Serial.println(buffer);
        return String(buffer);
      }
      delay(50);
    }
    Serial.println("No response in this attempt");
  }
  
  Serial.println("Server discovery failed after 3 attempts");
  return "";
}

void checkForResetCondition() {
  if (digitalRead(bootButtonPin) == LOW) {
    delay(100); // Debounce
    unsigned long startTime = millis();
    while (digitalRead(bootButtonPin) == LOW) {
      if (millis() - startTime > 3000) {
        triggerReset();
        return;
      }
    }
  }
}

void triggerReset() {
  Serial.println("Factory reset triggered!");
  digitalWrite(ledPin, HIGH);
  
  Config blank = {0};
  EEPROM.put(0, blank);
  EEPROM.commit();
  
  delay(1000);
  digitalWrite(ledPin, LOW);
  resetTriggered = true;
  ESP.restart();
}

void startCaptivePortal() {
  improvedCaptivePortal();
}

void improvedCaptivePortal() {
  Serial.println("Starting improved captive portal...");
  
  // Use a more recognizable AP name
  WiFi.softAP("EMERGENCY ALERT SETUP");
  IPAddress myIP = WiFi.softAPIP();
  Serial.print("AP IP address: ");
  Serial.println(myIP);
  
  // Standard DNS port
  dnsServer.start(53, "*", myIP);
  
  server.on("/", handleRoot);
  server.on("/save", HTTP_POST, handleSave);
  server.on("/generate_204", handleRoot);  // Android captive portal detection
  server.on("/favicon.ico", handleRoot);   // Browser icon request
  
  // Handle common captive portal detection URLs
  server.on("/hotspot-detect.html", handleRoot); // iOS/macOS
  server.on("/ncsi.txt", handleRoot);            // Windows
  server.on("/connecttest.txt", handleRoot);     // Windows
  
  server.onNotFound([]() {
    server.sendHeader("Location", "http://192.168.4.1/", true);
    server.send(302, "text/plain", "");
  });
  
  server.begin();
  Serial.println("HTTP server started");
}

void handleRoot() {
  String html = R"=====(
  <!DOCTYPE html>
  <html>
  <head>
    <title>Device Setup</title>
    <meta name="viewport" content="width=device-width, initial-scale=1">
    <style>
      body { font-family: Arial, sans-serif; max-width: 400px; margin: 0 auto; padding: 20px; }
      h1 { color: #444; text-align: center; }
      form { background: #f9f9f9; padding: 20px; border-radius: 5px; }
      input { width: 100%; padding: 10px; margin: 8px 0; box-sizing: border-box; }
      input[type=submit] { background: #4CAF50; color: white; border: none; }
    </style>
  </head>
  <body>
    <h1>Emergency Alert Setup</h1>
    <form action="/save" method="post">
      <label for="ssid">WiFi Network:</label>
      <input type="text" id="ssid" name="ssid" required placeholder="Your WiFi name">
      <label for="password">WiFi Password:</label>
      <input type="password" id="password" name="password" placeholder="Your WiFi password">
      <label for="deviceName">Device Name:</label>
      <input type="text" id="deviceName" name="deviceName" required placeholder="e.g., John's Device">
      <input type="submit" value="Save Configuration">
    </form>
  </body>
  </html>
  )=====";
  server.send(200, "text/html", html);
}

void handleSave() {
  strncpy(config.ssid, server.arg("ssid").c_str(), sizeof(config.ssid));
  strncpy(config.password, server.arg("password").c_str(), sizeof(config.password));
  strncpy(config.deviceName, server.arg("deviceName").c_str(), sizeof(config.deviceName));
  config.configured = true;
  
  EEPROM.put(0, config);
  EEPROM.commit();
  
  server.send(200, "text/html", 
    "<h1>Configuration Saved!</h1><p>Device will restart and connect to your network.</p>");
  delay(2000);
  ESP.restart();
}

void connectToWiFi() {
  enhancedWiFiConnect(); // Call the function but don't return its value
}

bool enhancedWiFiConnect() {
  Serial.println("Connecting to WiFi: " + String(config.ssid));
  
  WiFi.disconnect();
  delay(100);
  WiFi.begin(config.ssid, config.password);
  
  int attempts = 0;
  while (WiFi.status() != WL_CONNECTED && attempts < 20) {
    delay(500);
    Serial.print(".");
    attempts++;
  }
  Serial.println("");
  
  if (WiFi.status() == WL_CONNECTED) {
    printNetworkInfo();
    
    // Now check for server availability
    String serverIP = discoverServer();
    if (serverIP.isEmpty()) {
      Serial.println("Server unavailable. LED will indicate disconnected state.");
      serverConnected = false;
      // Continue blinking but at slower rate to indicate server disconnect
      isBlinking = true;
      return true;
    } else {
      Serial.println("Server found at: " + serverIP);
      serverConnected = true;
      // Stop blinking, server is available
      blinkLED(true);
      return true;
    }
  } else {
    Serial.println("WiFi connection failed! Starting config portal...");
    config.configured = false;
    EEPROM.put(0, config);
    EEPROM.commit();
    serverConnected = false;
    startCaptivePortal();
    return false;
  }
}

void printNetworkInfo() {
  Serial.println("\n--- Network Diagnostics ---");
  Serial.print("WiFi Status: ");
  switch (WiFi.status()) {
    case WL_CONNECTED: Serial.println("Connected"); break;
    case WL_NO_SHIELD: Serial.println("No WiFi shield"); break;
    case WL_IDLE_STATUS: Serial.println("Idle"); break;
    case WL_NO_SSID_AVAIL: Serial.println("No SSID available"); break;
    case WL_SCAN_COMPLETED: Serial.println("Scan completed"); break;
    case WL_CONNECT_FAILED: Serial.println("Connection failed"); break;
    case WL_CONNECTION_LOST: Serial.println("Connection lost"); break;
    case WL_DISCONNECTED: Serial.println("Disconnected"); break;
    default: Serial.println("Unknown"); break;
  }
  
  if (WiFi.status() == WL_CONNECTED) {
    Serial.print("IP Address: "); Serial.println(WiFi.localIP());
    Serial.print("Subnet Mask: "); Serial.println(WiFi.subnetMask());
    Serial.print("Gateway IP: "); Serial.println(WiFi.gatewayIP());
    Serial.print("DNS Server: "); Serial.println(WiFi.dnsIP());
    Serial.print("Signal Strength (RSSI): "); Serial.println(WiFi.RSSI());
  }
  
  Serial.print("Server Connected: "); Serial.println(serverConnected ? "Yes" : "No");
  Serial.println("----------------------------");
}

void networkDiagnostics() {
  Serial.println("\n====== EMERGENCY ALERT SYSTEM DIAGNOSTICS ======");
  Serial.print("Device Name: "); 
  if (config.configured) {
    Serial.println(config.deviceName);
  } else {
    Serial.println("Not configured");
  }
  Serial.print("Configured: "); Serial.println(config.configured ? "Yes" : "No");
  
  if (config.configured) {
    Serial.print("WiFi SSID: "); Serial.println(config.ssid);
    // Don't print the password for security
  }
  
  printNetworkInfo();
  Serial.println("===============================================");
}
